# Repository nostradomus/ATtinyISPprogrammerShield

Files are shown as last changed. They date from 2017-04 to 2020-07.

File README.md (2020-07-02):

# ATtiny ISP programmer shield for Arduino UNO boards


## What

This repo provides you with all necessary info (and files) to build an Arduino shield to program Atmel's **attiny** 𝜇-controllers. For that matter, the underlying Arduino board should be loaded with the ISP-programmer sketch (built-in example).

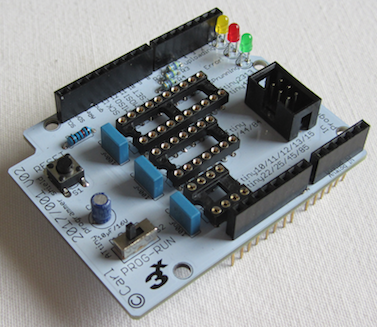
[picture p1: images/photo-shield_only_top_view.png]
Shield - topview
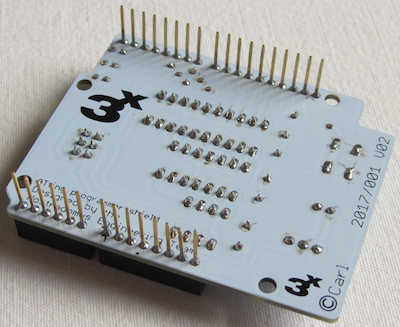
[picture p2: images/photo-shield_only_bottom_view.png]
Shield - bottomview
 

## Why

Often, one of these "tiny" chips is largely powerful enough for the design of small projects. During the design phase, I however got tired of wiring up things on a breadboard. As (like many people) I was having a spare UNO, which could serve as an ISP programmer, I decided to design a minimalistic shield to fit on top of it.  

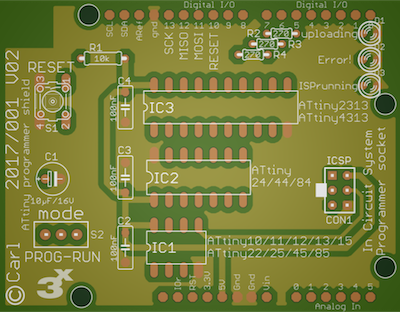
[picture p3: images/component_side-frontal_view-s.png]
PCB - component side
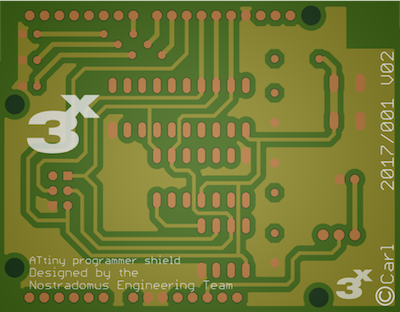
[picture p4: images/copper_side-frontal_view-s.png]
PCB - copper side
 

## How

The shield has been designed with EAGLE from AutoDesk/CadSoft. This shield [project](eagle-files/) can be opened with the free version [(download here)](http://www.autodesk.com/products/eagle/free-download). In order to keep things simple, the V1 PCB can be etched single-sided, as the top-layer only contains a couple of short connections (which can easily be replaced by wire-bridges). The V2 PCB (a real double-sided version) has optimised routing and ground-pours. Only [through-hole components](BOM.md) have been used in order to make the built also feasible for any beginner. In the [pdf-folder](pdf-files/) of this repo pdf versions of all important EAGLE views are available, for those not wanting to install EAGLE. Pay attention to print the bottom and top-layer layouts **without re-sizing** (1:1). To have the printed circuit board built by a commercial PCB-shop, the [gerber-files](gerber-files/) are also available.

Currently, unpopulated V2 boards are still available from our workshop. If interested, [contact us via   :email:](http://nostradomus.ddns.net/contactform.html).

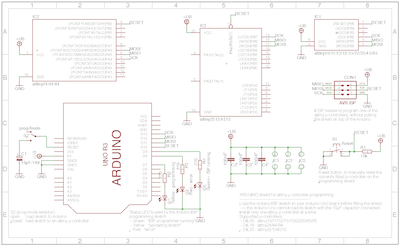
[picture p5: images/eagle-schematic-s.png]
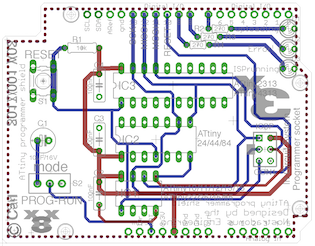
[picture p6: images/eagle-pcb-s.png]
 

## Technical details

### What’s on the board

The board is fit with 3 IC sockets (8, 14 and 20 pin), for the 3 types attiny’s. **Only one chip should be fit at a time** :exclamation: On the prototype, pin headers with double functionality have been mounted. Pins on the bottom-side to fit on the Arduino board, and feed-through female headers on the top for easy access of all Arduino connections.
The push button, is connected to the reset lines of the attiny’s with a 10kΩ pull-up resistor. When the shield is cut correctly, the reset button for the Arduino UNO itself should still be accessible. In order to make the Arduino Uno work as an ISP programmer a 10µF capacitor needs to be connected on its reset-line.
Three LED’s are available to visualise the correct functionality of the programming procedure.
An optional AVR ISP socket has been foreseen in order to use the shield as stand-alone with a commercial programmer.

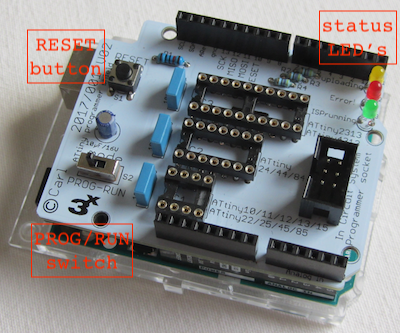
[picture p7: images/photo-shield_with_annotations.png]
V2 shield with text annotations
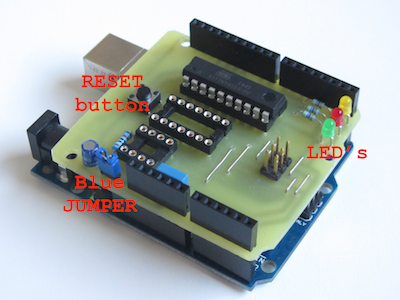
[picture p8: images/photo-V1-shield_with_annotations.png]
V1 shield with text annotations
 

#### BOM - bill of materials

Part | Value | Package | Description  
---- | ----- | ------- | -----------                            
R1     | 10kΩ           | 0207/7         | resistor                                            
R2,3,4 | 270Ω           | 0207/7         | resistor                                            
C1     | 10µF/16V       | E2,5-6E        | polarized capacitor                                 
C2,3,4 | 100nF          | C050-025X075   | capacitor                                           
LED1   | 3mm yellow     | 3mm            | LED                              
LED2   | 3mm red        | 3mm            | LED                              
LED3   | 3mm green      | 3mm            | LED                                                                                             
IC1    | 8-pin          | DIL08          | IC socket                                                            
IC2    | 14-pin         | DIL14          | IC socket                                                                     
IC3    | 20-pin         | DIL20          | IC socket                                                                     
ICSP1  | 2x3 pin-header | 2x3            | AVR ISP-6 Serial Programming Header (optional)                                 
S1     | momentary      | 6x6x6mm        | momentary tact push button
S2	    | SPDT	          | MINI SWITCH 90 | mini toggle switch
CON1   | 6-pin          | SIL06          | long needle female stackable pin header strip
CON2,3 | 8-pin          | SIL08          | long needle female stackable pin header strip
CON4   | 10-pin         | SIL10          | long needle female stackable pin header strip

### How things work

First the the [ISP-programmer sketch](sketches/ArduinoISP.ino) (built-in example) should be loaded to the Arduino UNO board. During that operation, switch S2 should be set to 'PROG' (or remove the blue jumper JP1 on a V1 board). Select “Arduino Uno” as target board in the tools-menu. Load the ISP-programmer sketch with the “UPLOAD” button. Once loaded, the jumper can be put back to send your a sketch to your attiny 𝜇-controller.

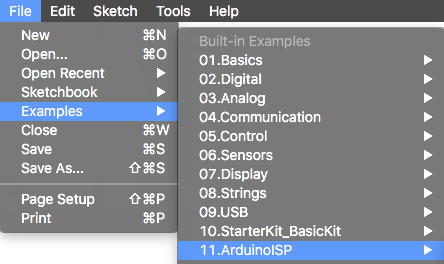
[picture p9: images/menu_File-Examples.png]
ISP example sketch
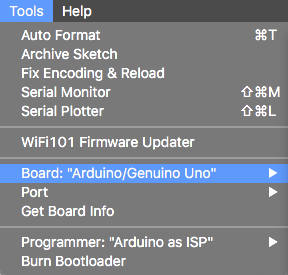
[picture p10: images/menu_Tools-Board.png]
Board selection
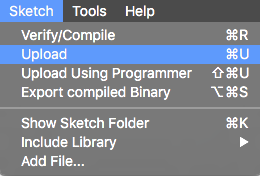
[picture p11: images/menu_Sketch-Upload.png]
Upload
  

To load a sketch to your attiny chip, make sure that the correct target board is selected in the tools-menu (you might need to download a specific library -> tools-menu, board manager). This time, use the “UPLOAD USING PROGRAMMER” option from the sketch-menu.

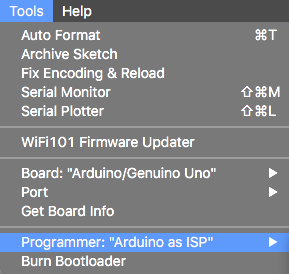
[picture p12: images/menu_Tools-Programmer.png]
Programmer selection
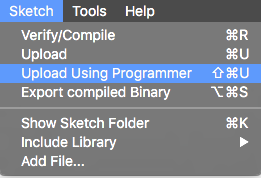
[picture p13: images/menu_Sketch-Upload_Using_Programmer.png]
Upload Using Programmer
 

The 3 LED’s will tell you how things are going :
 - Green  : ISP programmer running
 - Yellow : uploading sketch
 - Red    : error  

### Proof of concept

So far, I have tested the shield with the below list of 𝜇-controllers :
 - attiny84
 - attiny85
 - attiny2313
 - attiny4313

 Any pin-compatible 𝜇-controller should work as well :
 - 8-pin  : attiny10/11/12/13/15/22/25/45/85
 - 14-pin : attiny24/44/84
 - 20-pin : attiny2313/4313
 (on condition of using the correct settings in your Arduino programming environment)

## Contributors

If you are having any good suggestions, just drop me a line [:email:](http://nostradomus.ddns.net/contactform.html).
If feasible, I'll be happy to implement any proposed improvements.
And if you are having lots of time, I'll be happy to share the work with you ;-).

## :globe_with_meridians: License

At this moment, there is no specific license attached to this project.

So, today, if you like it, have fun with it (at your own risk of course :-D), and especially, be creative.

Oh, and when using anything from this repository, it is highly appreciated if you mention its origin.

If you would like to use any of this work (or the whole project) for commercial use, first [contact us :email:](http://nostradomus.ddns.net/contactform.html), so we can add the appropriate license, which best fits your business.

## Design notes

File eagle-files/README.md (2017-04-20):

This folder contains all files required to open the project in the EAGLE PCB software [(download here)](http://www.autodesk.com/products/eagle/free-download) : 

 - .epf : the project file as main entry point (is connected with the description file)
 - .sch : schematic file
 - .brd : pcb layout file
 
 These files should (grouped in a folder) either be copied in Eagle's project directory (see below image of the settings window). The Eagle directory settings also accept multiple paths. The Eagle syntax requires columns as path separators.

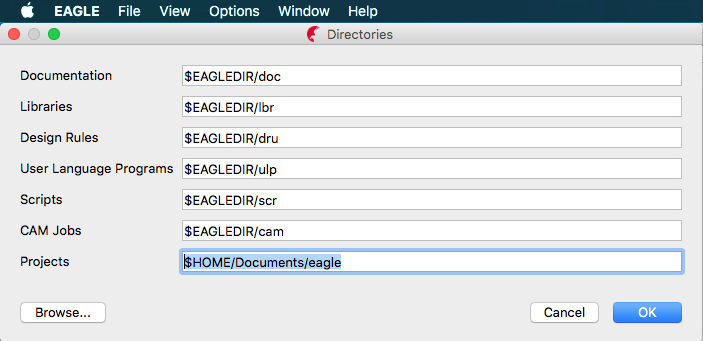
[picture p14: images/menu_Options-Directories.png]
Directory settings


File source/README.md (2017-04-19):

### This folder contains Arduino sketches related to the programming shield : 

 - The **ArduinoISP.ino** sketch has been added for informational purposes only. It has been copied from the Arduino.cc application, version 1.8 for MacOS. Please prioritise the use of the built-in example in the IDE on your system.

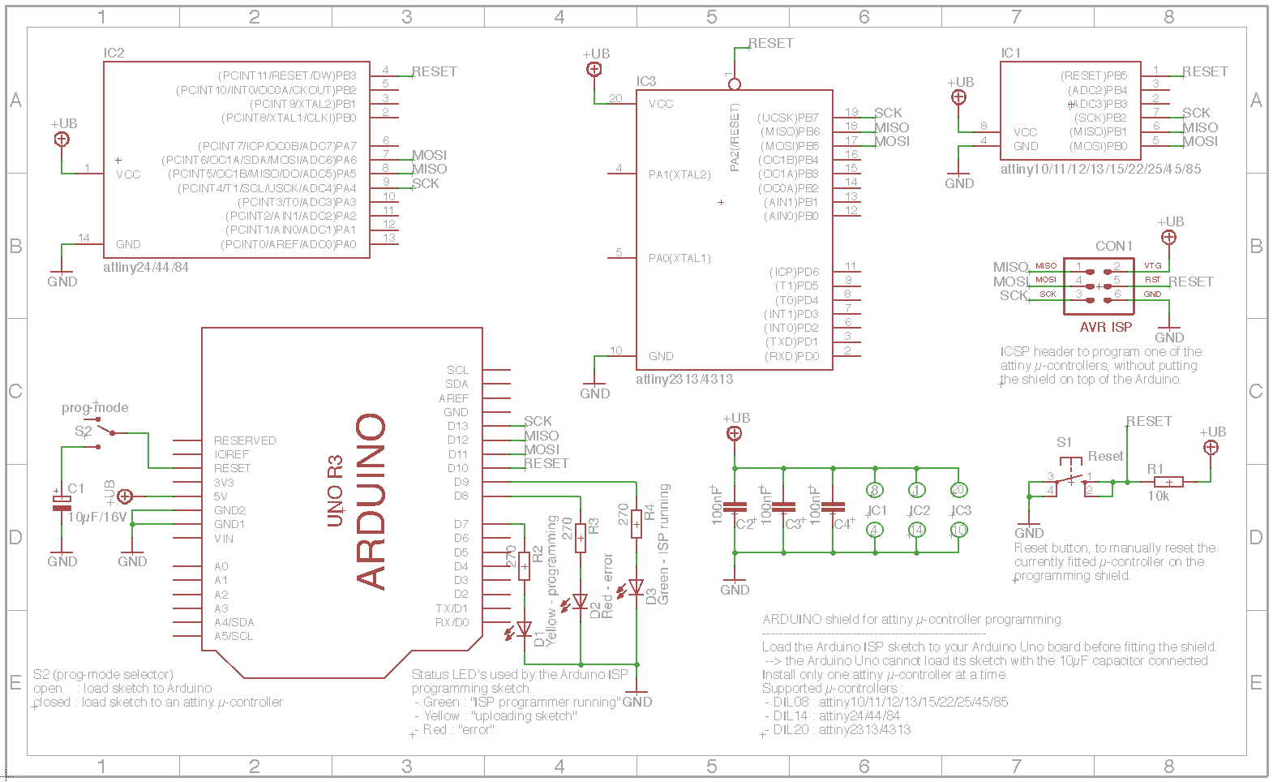
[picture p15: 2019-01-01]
images/eagle-schematic.png

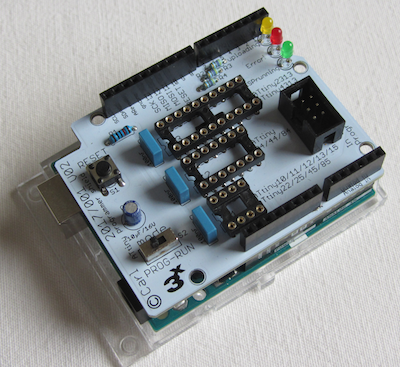
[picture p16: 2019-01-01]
images/photo-shield_fit_on_arduino-2.png

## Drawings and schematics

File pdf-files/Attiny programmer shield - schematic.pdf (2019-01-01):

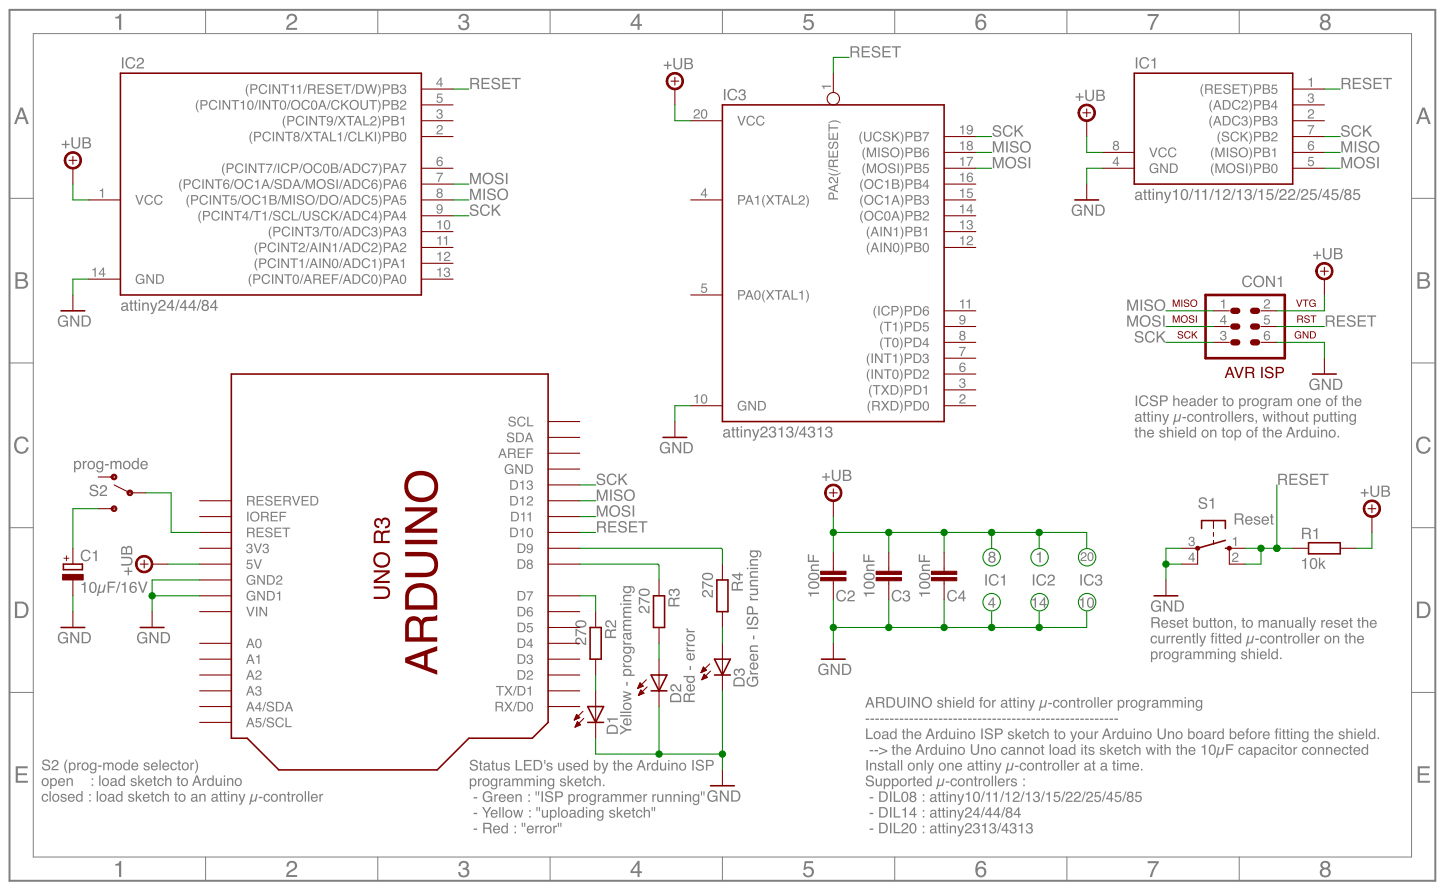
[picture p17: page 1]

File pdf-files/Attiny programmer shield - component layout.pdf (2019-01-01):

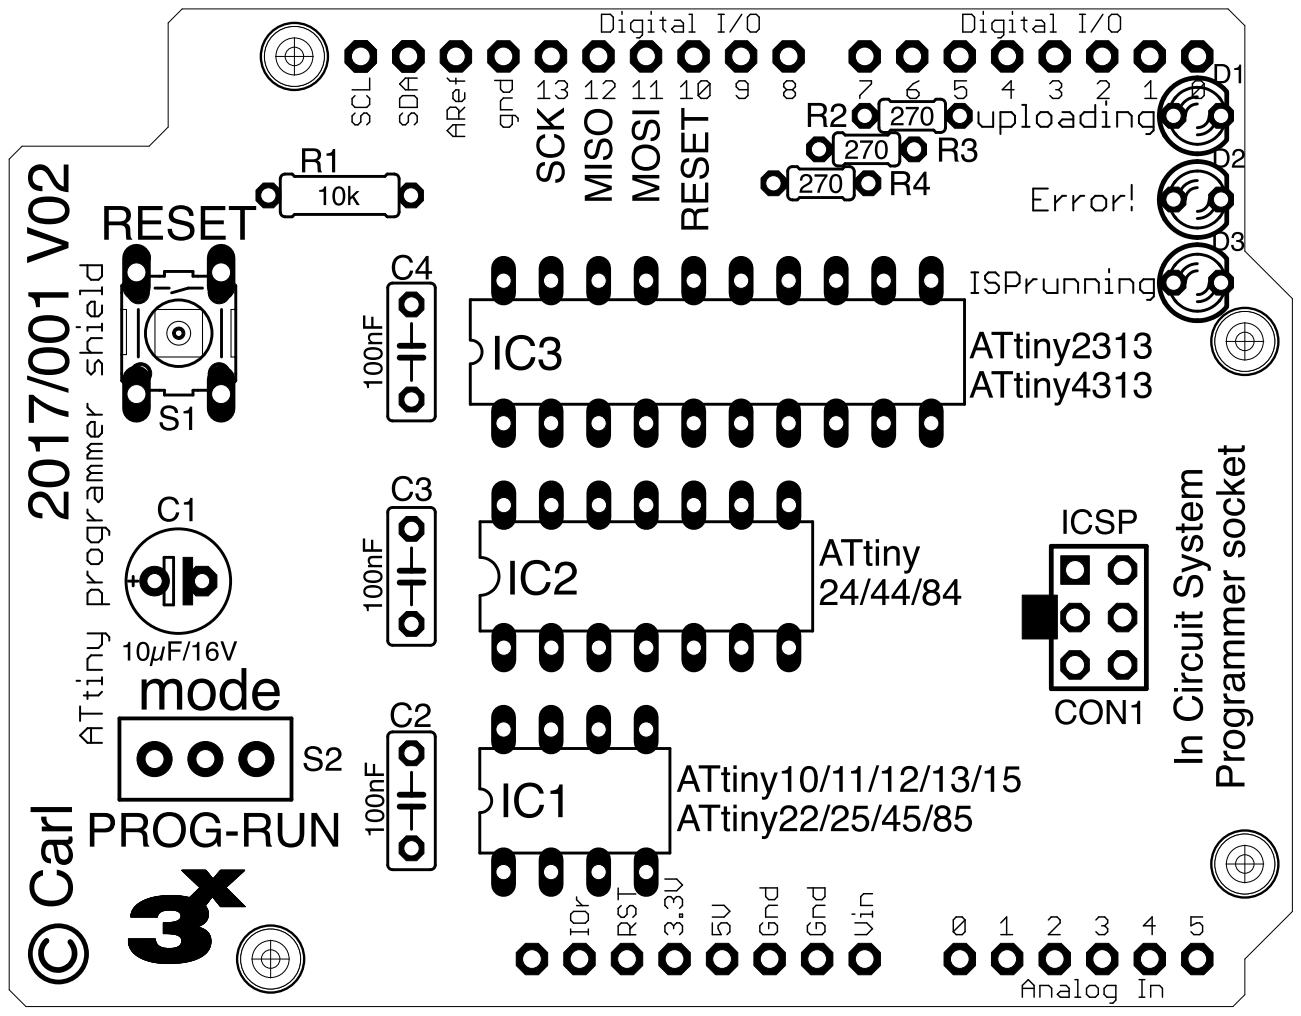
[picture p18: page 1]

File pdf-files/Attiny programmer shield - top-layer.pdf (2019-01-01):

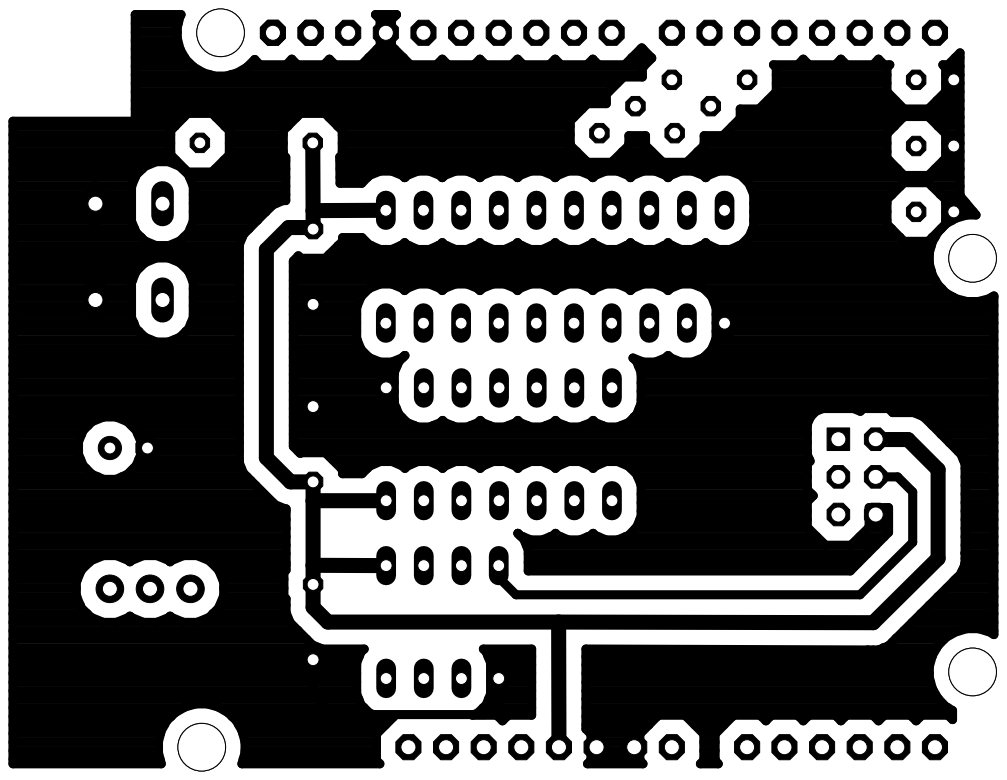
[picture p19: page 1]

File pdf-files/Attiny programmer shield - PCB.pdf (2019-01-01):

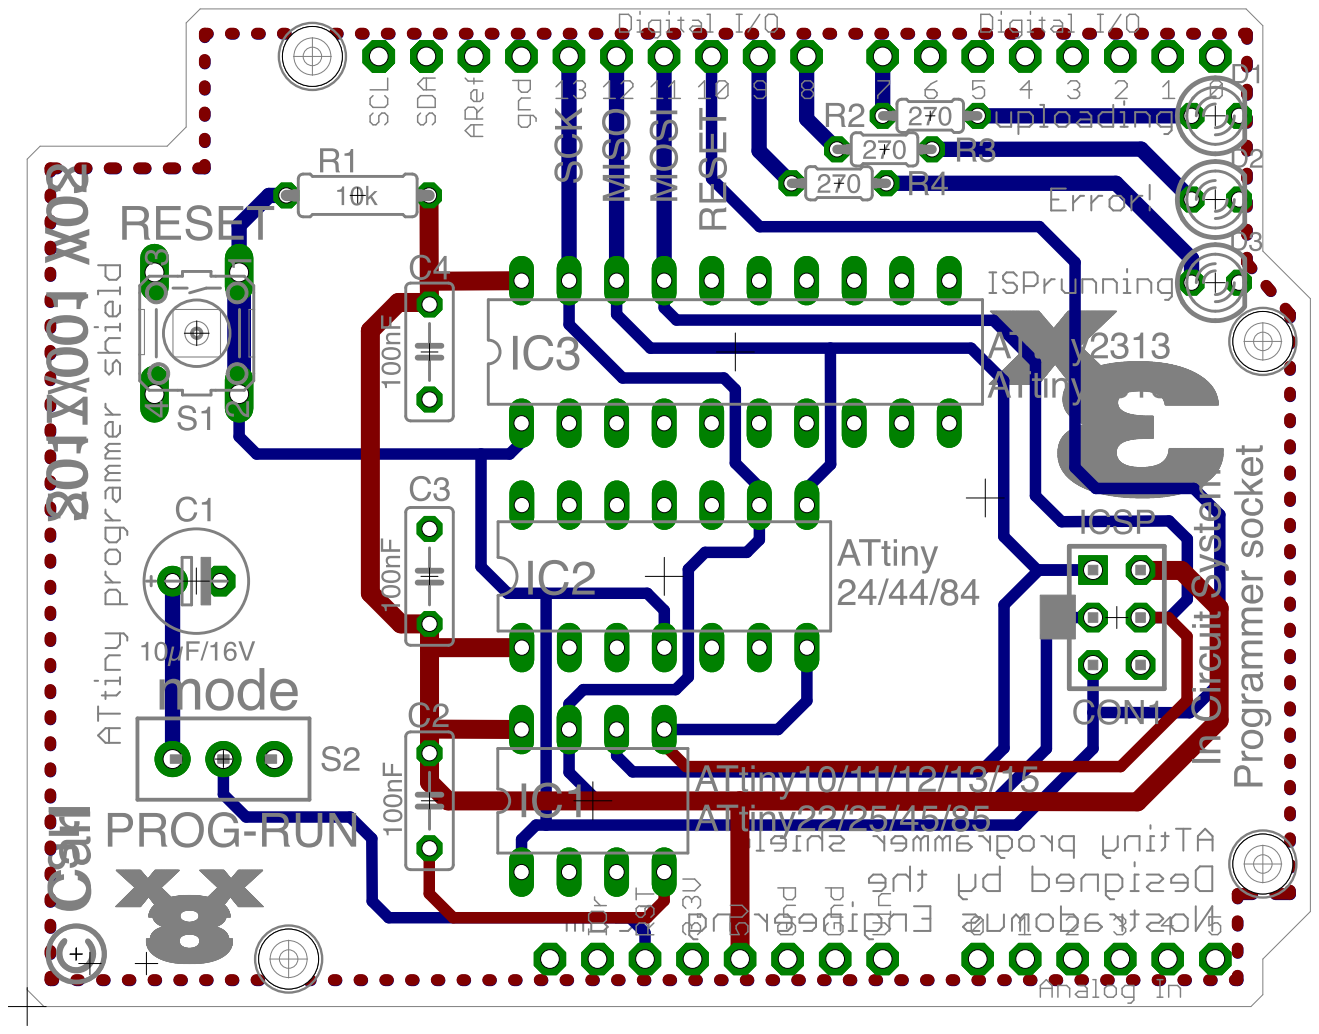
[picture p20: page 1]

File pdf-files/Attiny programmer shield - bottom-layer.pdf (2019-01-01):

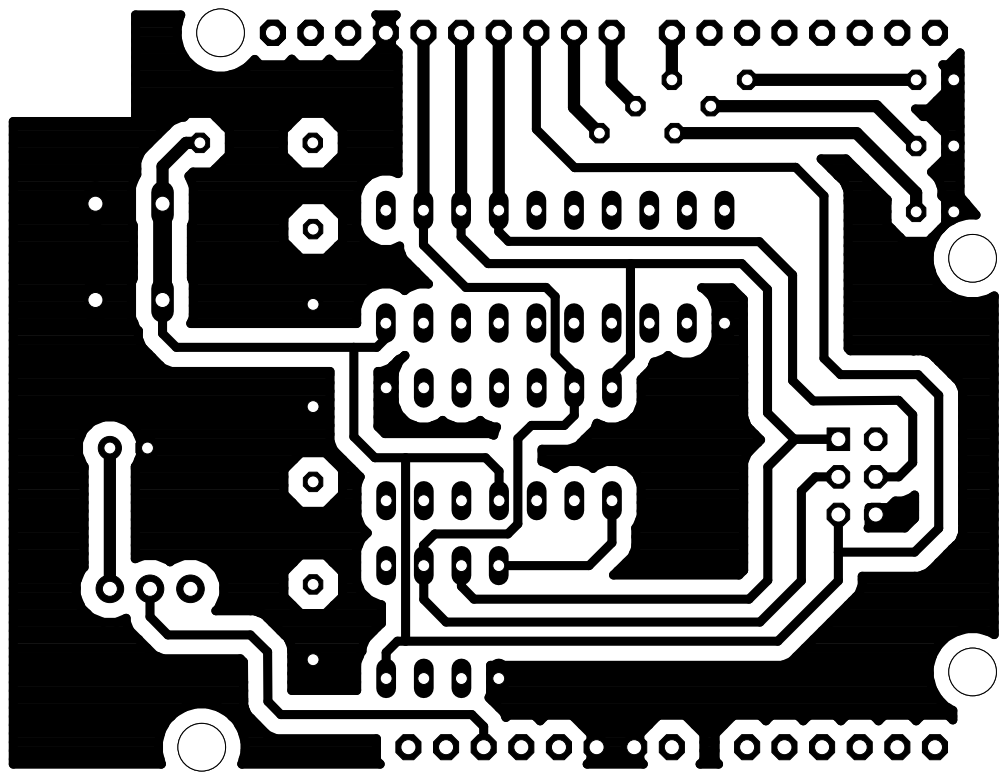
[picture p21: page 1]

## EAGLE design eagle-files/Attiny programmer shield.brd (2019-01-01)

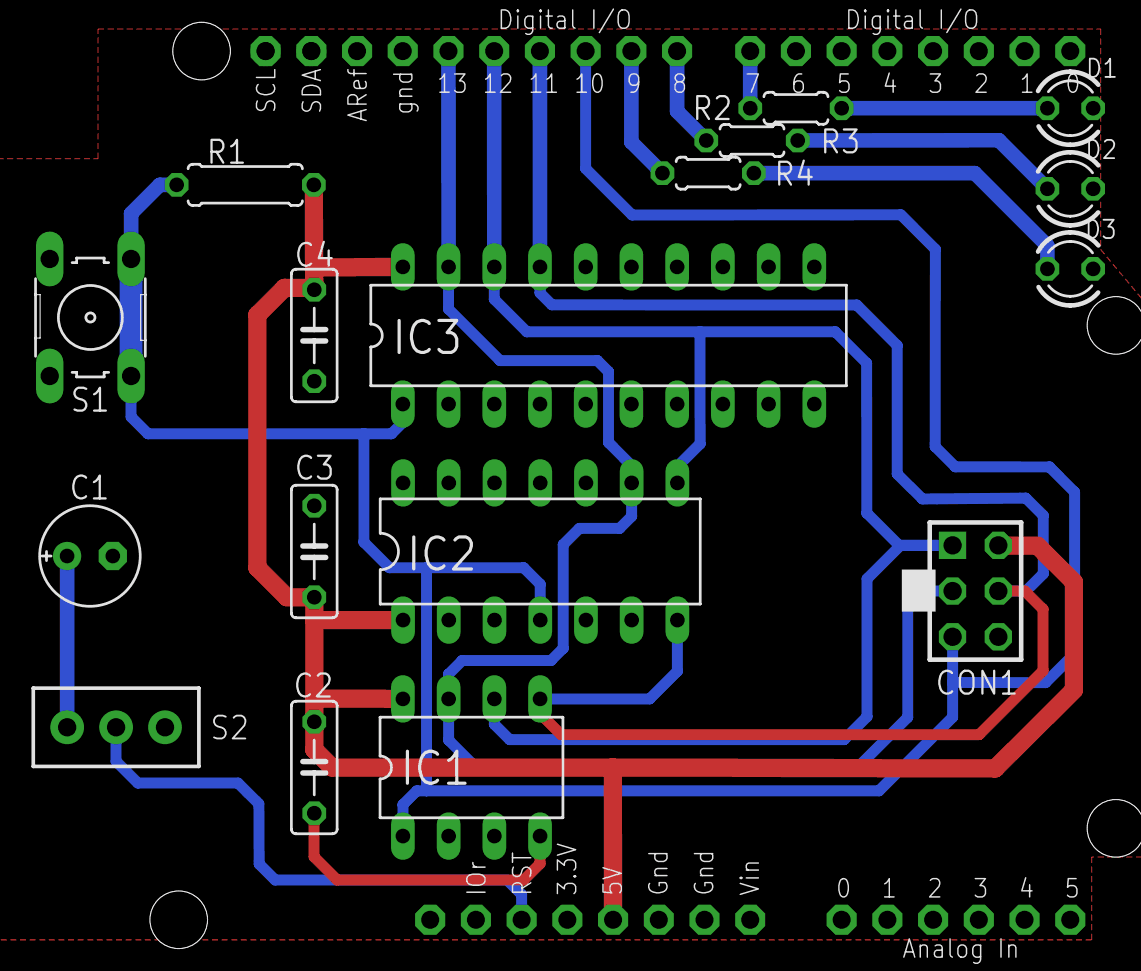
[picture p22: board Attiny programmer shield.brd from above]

Board: 2 copper layers, 23 parts (0 on the bottom side), 14 nets.

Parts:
C1: 10µF/16V; E2,5-6E
C2, C3, C4: 100nF; C050-025X075
CON1: ICSP; AVR-ISP-6
D1: Yellow - programming; LED3MM
D2: Red - error; LED3MM
D3: Green - ISP running; LED3MM
IC1: attiny10/11/12/13/15/22/25/45/85; DIL08
IC2: attiny24/44/84; DIL14
IC3: attiny2313/4313; DIL20
R1: 10k; 0207/7
R2, R3, R4: 270; 0204/5
S1: Reset; B3F-10XX
S2: prog-mode; MINI_SPDT_SWITCH-9.0X4.0MM
U$1: Arduino Uno; ARDUINO-R3
U$2: COPYRIGHT-LOGO-3-B
U$3: 3X-LOGO-10-B
U$4: COPYRIGHT-LOGO-3-T
U$5: 3X-LOGO-5-B
U$6: 3X-LOGO-5-T

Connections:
+UB: C2.2, C3.2, C4.2, CON1.2, IC1.8, IC2.1, IC3.20, R1.2, U$1.5V
GND: C1.-, C2.1, C3.1, C4.1, CON1.6, D1.K, D2.K, D3.K, IC1.4, IC2.14, IC3.10, S1.3, S1.4, U$1.GND, U$1.GND1, U$1.GND2
MISO: CON1.1, IC1.6, IC2.8, IC3.18, U$1.D12
MOSI: CON1.4, IC1.5, IC2.7, IC3.17, U$1.D11
unnamed: C1.+, S2.3
unnamed: R4.1, U$1.D9
unnamed: R2.1, U$1.D7
unnamed: R3.1, U$1.D8
unnamed: D1.A, R2.2
unnamed: D2.A, R3.2
unnamed: D3.A, R4.2
unnamed: S2.2, U$1.RESET
RESET: CON1.5, IC1.1, IC2.4, IC3.1, R1.1, S1.1, S1.2, U$1.D10
SCK: CON1.3, IC1.7, IC2.9, IC3.19, U$1.D13

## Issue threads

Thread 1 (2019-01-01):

Short between D11 and LED pin

ondras12345, 2019-01-01:
There is a short in the PCB design
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

nostradomus, 2019-01-01:
@ondras12345,
thank you for your remark.
Version V02 of this project has now been released, and does no longer contain the problem (short between LED3 and D11). All related files have been replaced in the repo, and readme's have been updated.

Closed 2019-01-01.

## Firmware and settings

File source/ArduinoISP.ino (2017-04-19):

// ArduinoISP
// Copyright (c) 2008-2011 Randall Bohn
// If you require a license, see
//     http://www.opensource.org/licenses/bsd-license.php
//
// This sketch turns the Arduino into a AVRISP
// using the following arduino pins:
//
// Pin 10 is used to reset the target microcontroller.
//
// By default, the hardware SPI pins MISO, MOSI and SCK pins are used
// to communicate with the target. On all Arduinos, these pins can be found
// on the ICSP/SPI header:
//
//               MISO °. . 5V (!) Avoid this pin on Due, Zero...
//               SCK   . . MOSI
//                     . . GND
//
// On some Arduinos (Uno,...), pins MOSI, MISO and SCK are the same pins
// as digital pin 11, 12 and 13, respectively. That is why many tutorials
// instruct you to hook up the target to these pins. If you find this wiring
// more practical, have a define USE_OLD_STYLE_WIRING. This will work even
// even when not using an Uno. (On an Uno this is not needed).
//
// Alternatively you can use any other digital pin by configuring software ('BitBanged')
// SPI and having appropriate defines for PIN_MOSI, PIN_MISO and PIN_SCK.
// 
// IMPORTANT: When using an Arduino that is not 5V tolerant (Due, Zero, ...)
// as the programmer, make sure to not expose any of the programmer's pins to 5V.
// A simple way to accomplish this is to power the complete system (programmer
// and target) at 3V3.
//
// Put an LED (with resistor) on the following pins:
// 9: Heartbeat   - shows the programmer is running
// 8: Error       - Lights up if something goes wrong (use red if that makes sense)
// 7: Programming - In communication with the slave
//

#include "Arduino.h"
#undef SERIAL


#define PROG_FLICKER true

// Configure SPI clock (in Hz).
// E.g. for an attiny @128 kHz: the datasheet states that both the high
// and low spi clock pulse must be > 2 cpu cycles, so take 3 cycles i.e.
// divide target f_cpu by 6:
//     #define SPI_CLOCK            (128000/6)
//
// A clock slow enough for an attiny85 @ 1MHz, is a reasonable default:

#define SPI_CLOCK 		(1000000/6)


// Select hardware or software SPI, depending on SPI clock.
// Currently only for AVR, for other archs (Due, Zero,...),
// hardware SPI is probably too fast anyway.

#if defined(ARDUINO_ARCH_AVR)

#if SPI_CLOCK > (F_CPU / 128)
#define USE_HARDWARE_SPI
#endif

#endif

// Configure which pins to use:

// The standard pin configuration.
#ifndef ARDUINO_HOODLOADER2 

#define RESET     10 // Use pin 10 to reset the target rather than SS
#define LED_HB    9
#define LED_ERR   8
#define LED_PMODE 7

// Uncomment following line to use the old Uno style wiring
// (using pin 11, 12 and 13 instead of the SPI header) on Leonardo, Due...

// #define USE_OLD_STYLE_WIRING

#ifdef USE_OLD_STYLE_WIRING

#define PIN_MOSI	11
#define PIN_MISO	12
#define PIN_SCK		13

#endif

// HOODLOADER2 means running sketches on the atmega16u2 
// serial converter chips on Uno or Mega boards.
// We must use pins that are broken out:
#else 

#define RESET     	4
#define LED_HB    	7
#define LED_ERR   	6
#define LED_PMODE 	5

#endif

// By default, use hardware SPI pins:
#ifndef PIN_MOSI
#define PIN_MOSI 	MOSI
#endif

#ifndef PIN_MISO
#define PIN_MISO 	MISO
#endif

#ifndef PIN_SCK
#define PIN_SCK 	SCK
#endif

// Force bitbanged SPI if not using the hardware SPI pins:
#if (PIN_MISO != MISO) ||  (PIN_MOSI != MOSI) || (PIN_SCK != SCK)
#undef USE_HARDWARE_SPI
#endif


// Configure the serial port to use.
//
// Prefer the USB virtual serial port (aka. native USB port), if the Arduino has one:
//   - it does not autoreset (except for the magic baud rate of 1200).
//   - it is more reliable because of USB handshaking.
//
// Leonardo and similar have an USB virtual serial port: 'Serial'.
// Due and Zero have an USB virtual serial port: 'SerialUSB'.
//
// On the Due and Zero, 'Serial' can be used too, provided you disable autoreset.
// To use 'Serial': #define SERIAL Serial

#ifdef SERIAL_PORT_USBVIRTUAL
#define SERIAL SERIAL_PORT_USBVIRTUAL
#else
#define SERIAL Serial
#endif


// Configure the baud rate:

#define BAUDRATE	19200
// #define BAUDRATE	115200
// #define BAUDRATE	1000000


#define HWVER 2
#define SWMAJ 1
#define SWMIN 18

// STK Definitions
#define STK_OK      0x10
#define STK_FAILED  0x11
#define STK_UNKNOWN 0x12
#define STK_INSYNC  0x14
#define STK_NOSYNC  0x15
#define CRC_EOP     0x20 //ok it is a space...

void pulse(int pin, int times);

#ifdef USE_HARDWARE_SPI
#include "SPI.h"
#else

#define SPI_MODE0 0x00

class SPISettings {
public:
  // clock is in Hz
  SPISettings(uint32_t clock, uint8_t bitOrder, uint8_t dataMode) : clock(clock){
    (void) bitOrder;
    (void) dataMode;
  };

private:
  uint32_t clock;

friend class BitBangedSPI;
};

class BitBangedSPI {
public:
  void begin() {
    digitalWrite(PIN_SCK, LOW);
    digitalWrite(PIN_MOSI, LOW);
    pinMode(PIN_SCK, OUTPUT);
    pinMode(PIN_MOSI, OUTPUT);
    pinMode(PIN_MISO, INPUT);
  }

  void beginTransaction(SPISettings settings) {
    pulseWidth = (500000 + settings.clock - 1) / settings.clock;
    if (pulseWidth == 0)
      pulseWidth = 1;
  }

  void end() {}

  uint8_t transfer (uint8_t b) {
    for (unsigned int i = 0; i < 8; ++i) {
      digitalWrite(PIN_MOSI, (b & 0x80) ? HIGH : LOW);
      digitalWrite(PIN_SCK, HIGH);
      delayMicroseconds(pulseWidth);
      b = (b << 1) | digitalRead(PIN_MISO);
      digitalWrite(PIN_SCK, LOW); // slow pulse
      delayMicroseconds(pulseWidth);
    }
    return b;
  }

private:
  unsigned long pulseWidth; // in microseconds
};

static BitBangedSPI SPI;

#endif

void setup() {
  SERIAL.begin(BAUDRATE);

  pinMode(LED_PMODE, OUTPUT);
  pulse(LED_PMODE, 2);
  pinMode(LED_ERR, OUTPUT);
  pulse(LED_ERR, 2);
  pinMode(LED_HB, OUTPUT);
  pulse(LED_HB, 2);

}

int error = 0;
int pmode = 0;
// address for reading and writing, set by 'U' command
unsigned int here;
uint8_t buff[256]; // global block storage

#define beget16(addr) (*addr * 256 + *(addr+1) )
typedef struct param {
  uint8_t devicecode;
  uint8_t revision;
  uint8_t progtype;
  uint8_t parmode;
  uint8_t polling;
  uint8_t selftimed;
  uint8_t lockbytes;
  uint8_t fusebytes;
  uint8_t flashpoll;
  uint16_t eeprompoll;
  uint16_t pagesize;
  uint16_t eepromsize;
  uint32_t flashsize;
}
parameter;

parameter param;

// this provides a heartbeat on pin 9, so you can tell the software is running.
uint8_t hbval = 128;
int8_t hbdelta = 8;
void heartbeat() {
  static unsigned long last_time = 0;
  unsigned long now = millis();
  if ((now - last_time) < 40)
    return;
  last_time = now;
  if (hbval > 192) hbdelta = -hbdelta;
  if (hbval < 32) hbdelta = -hbdelta;
  hbval += hbdelta;
  analogWrite(LED_HB, hbval);
}

static bool rst_active_high;

void reset_target(bool reset) {
  digitalWrite(RESET, ((reset && rst_active_high) || (!reset && !rst_active_high)) ? HIGH : LOW);
}

void loop(void) {
  // is pmode active?
  if (pmode) {
    digitalWrite(LED_PMODE, HIGH);
  } else {
    digitalWrite(LED_PMODE, LOW);
  }
  // is there an error?
  if (error) {
    digitalWrite(LED_ERR, HIGH);
  } else {
    digitalWrite(LED_ERR, LOW);
  }

  // light the heartbeat LED
  heartbeat();
  if (SERIAL.available()) {
    avrisp();
  }
}

uint8_t getch() {
  while (!SERIAL.available());
  return SERIAL.read();
}
void fill(int n) {
  for (int x = 0; x < n; x++) {
    buff[x] = getch();
  }
}

#define PTIME 30
void pulse(int pin, int times) {
  do {
    digitalWrite(pin, HIGH);
    delay(PTIME);
    digitalWrite(pin, LOW);
    delay(PTIME);
  } while (times--);
}

void prog_lamp(int state) {
  if (PROG_FLICKER) {
    digitalWrite(LED_PMODE, state);
  }
}

uint8_t spi_transaction(uint8_t a, uint8_t b, uint8_t c, uint8_t d) {
  SPI.transfer(a);
  SPI.transfer(b);
  SPI.transfer(c);
  return SPI.transfer(d);
}

void empty_reply() {
  if (CRC_EOP == getch()) {
    SERIAL.print((char)STK_INSYNC);
    SERIAL.print((char)STK_OK);
  } else {
    error++;
    SERIAL.print((char)STK_NOSYNC);
  }
}

void breply(uint8_t b) {
  if (CRC_EOP == getch()) {
    SERIAL.print((char)STK_INSYNC);
    SERIAL.print((char)b);
    SERIAL.print((char)STK_OK);
  } else {
    error++;
    SERIAL.print((char)STK_NOSYNC);
  }
}

void get_version(uint8_t c) {
  switch (c) {
    case 0x80:
      breply(HWVER);
      break;
    case 0x81:
      breply(SWMAJ);
      break;
    case 0x82:
      breply(SWMIN);
      break;
    case 0x93:
      breply('S'); // serial programmer
      break;
    default:
      breply(0);
  }
}

void set_parameters() {
  // call this after reading paramter packet into buff[]
  param.devicecode = buff[0];
  param.revision   = buff[1];
  param.progtype   = buff[2];
  param.parmode    = buff[3];
  param.polling    = buff[4];
  param.selftimed  = buff[5];
  param.lockbytes  = buff[6];
  param.fusebytes  = buff[7];
  param.flashpoll  = buff[8];
  // ignore buff[9] (= buff[8])
  // following are 16 bits (big endian)
  param.eeprompoll = beget16(&buff[10]);
  param.pagesize   = beget16(&buff[12]);
  param.eepromsize = beget16(&buff[14]);

  // 32 bits flashsize (big endian)
  param.flashsize = buff[16] * 0x01000000
                    + buff[17] * 0x00010000
                    + buff[18] * 0x00000100
                    + buff[19];

  // avr devices have active low reset, at89sx are active high
  rst_active_high = (param.devicecode >= 0xe0);
}

void start_pmode() {

  // Reset target before driving PIN_SCK or PIN_MOSI

  // SPI.begin() will configure SS as output,
  // so SPI master mode is selected.
  // We have defined RESET as pin 10,
  // which for many arduino's is not the SS pin.
  // So we have to configure RESET as output here,
  // (reset_target() first sets the correct level)
  reset_target(true);
  pinMode(RESET, OUTPUT);
  SPI.begin();
  SPI.beginTransaction(SPISettings(SPI_CLOCK, MSBFIRST, SPI_MODE0));

  // See avr datasheets, chapter "SERIAL_PRG Programming Algorithm":

  // Pulse RESET after PIN_SCK is low:
  digitalWrite(PIN_SCK, LOW);
  delay(20); // discharge PIN_SCK, value arbitrally chosen
  reset_target(false);
  // Pulse must be minimum 2 target CPU clock cycles
  // so 100 usec is ok for CPU speeds above 20KHz
  delayMicroseconds(100);
  reset_target(true);

  // Send the enable programming command:
  delay(50); // datasheet: must be > 20 msec
  spi_transaction(0xAC, 0x53, 0x00, 0x00);
  pmode = 1;
}

void end_pmode() {
  SPI.end();
  // We're about to take the target out of reset
  // so configure SPI pins as input
  pinMode(PIN_MOSI, INPUT);
  pinMode(PIN_SCK, INPUT);
  reset_target(false);
  pinMode(RESET, INPUT);
  pmode = 0;
}

void universal() {
  uint8_t ch;

  fill(4);
  ch = spi_transaction(buff[0], buff[1], buff[2], buff[3]);
  breply(ch);
}

void flash(uint8_t hilo, unsigned int addr, uint8_t data) {
  spi_transaction(0x40 + 8 * hilo,
                  addr >> 8 & 0xFF,
                  addr & 0xFF,
                  data);
}
void commit(unsigned int addr) {
  if (PROG_FLICKER) {
    prog_lamp(LOW);
  }
  spi_transaction(0x4C, (addr >> 8) & 0xFF, addr & 0xFF, 0);
  if (PROG_FLICKER) {
    delay(PTIME);
    prog_lamp(HIGH);
  }
}

unsigned int current_page() {
  if (param.pagesize == 32) {
    return here & 0xFFFFFFF0;
  }
  if (param.pagesize == 64) {
    return here & 0xFFFFFFE0;
  }
  if (param.pagesize == 128) {
    return here & 0xFFFFFFC0;
  }
  if (param.pagesize == 256) {
    return here & 0xFFFFFF80;
  }
  return here;
}


void write_flash(int length) {
  fill(length);
  if (CRC_EOP == getch()) {
    SERIAL.print((char) STK_INSYNC);
    SERIAL.print((char) write_flash_pages(length));
  } else {
    error++;
    SERIAL.print((char) STK_NOSYNC);
  }
}

uint8_t write_flash_pages(int length) {
  int x = 0;
  unsigned int page = current_page();
  while (x < length) {
    if (page != current_page()) {
      commit(page);
      page = current_page();
    }
    flash(LOW, here, buff[x++]);
    flash(HIGH, here, buff[x++]);
    here++;
  }

  commit(page);

  return STK_OK;
}

#define EECHUNK (32)
uint8_t write_eeprom(unsigned int length) {
  // here is a word address, get the byte address
  unsigned int start = here * 2;
  unsigned int remaining = length;
  if (length > param.eepromsize) {
    error++;
    return STK_FAILED;
  }
  while (remaining > EECHUNK) {
    write_eeprom_chunk(start, EECHUNK);
    start += EECHUNK;
    remaining -= EECHUNK;
  }
  write_eeprom_chunk(start, remaining);
  return STK_OK;
}
// write (length) bytes, (start) is a byte address
uint8_t write_eeprom_chunk(unsigned int start, unsigned int length) {
  // this writes byte-by-byte,
  // page writing may be faster (4 bytes at a time)
  fill(length);
  prog_lamp(LOW);
  for (unsigned int x = 0; x < length; x++) {
    unsigned int addr = start + x;
    spi_transaction(0xC0, (addr >> 8) & 0xFF, addr & 0xFF, buff[x]);
    delay(45);
  }
  prog_lamp(HIGH);
  return STK_OK;
}

void program_page() {
  char result = (char) STK_FAILED;
  unsigned int length = 256 * getch();
  length += getch();
  char memtype = getch();
  // flash memory @here, (length) bytes
  if (memtype == 'F') {
    write_flash(length);
    return;
  }
  if (memtype == 'E') {
    result = (char)write_eeprom(length);
    if (CRC_EOP == getch()) {
      SERIAL.print((char) STK_INSYNC);
      SERIAL.print(result);
    } else {
      error++;
      SERIAL.print((char) STK_NOSYNC);
    }
    return;
  }
  SERIAL.print((char)STK_FAILED);
  return;
}

uint8_t flash_read(uint8_t hilo, unsigned int addr) {
  return spi_transaction(0x20 + hilo * 8,
                         (addr >> 8) & 0xFF,
                         addr & 0xFF,
                         0);
}

char flash_read_page(int length) {
  for (int x = 0; x < length; x += 2) {
    uint8_t low = flash_read(LOW, here);
    SERIAL.print((char) low);
    uint8_t high = flash_read(HIGH, here);
    SERIAL.print((char) high);
    here++;
  }
  return STK_OK;
}

char eeprom_read_page(int length) {
  // here again we have a word address
  int start = here * 2;
  for (int x = 0; x < length; x++) {
    int addr = start + x;
    uint8_t ee = spi_transaction(0xA0, (addr >> 8) & 0xFF, addr & 0xFF, 0xFF);
    SERIAL.print((char) ee);
  }
  return STK_OK;
}

void read_page() {
  char result = (char)STK_FAILED;
  int length = 256 * getch();
  length += getch();
  char memtype = getch();
  if (CRC_EOP != getch()) {
    error++;
    SERIAL.print((char) STK_NOSYNC);
    return;
  }
  SERIAL.print((char) STK_INSYNC);
  if (memtype == 'F') result = flash_read_page(length);
  if (memtype == 'E') result = eeprom_read_page(length);
  SERIAL.print(result);
}

void read_signature() {
  if (CRC_EOP != getch()) {
    error++;
    SERIAL.print((char) STK_NOSYNC);
    return;
  }
  SERIAL.print((char) STK_INSYNC);
  uint8_t high = spi_transaction(0x30, 0x00, 0x00, 0x00);
  SERIAL.print((char) high);
  uint8_t middle = spi_transaction(0x30, 0x00, 0x01, 0x00);
  SERIAL.print((char) middle);
  uint8_t low = spi_transaction(0x30, 0x00, 0x02, 0x00);
  SERIAL.print((char) low);
  SERIAL.print((char) STK_OK);
}
//////////////////////////////////////////
//////////////////////////////////////////


////////////////////////////////////
////////////////////////////////////
void avrisp() {
  uint8_t ch = getch();
  switch (ch) {
    case '0': // signon
      error = 0;
      empty_reply();
      break;
    case '1':
      if (getch() == CRC_EOP) {
        SERIAL.print((char) STK_INSYNC);
        SERIAL.print("AVR ISP");
        SERIAL.print((char) STK_OK);
      }
      else {
        error++;
        SERIAL.print((char) STK_NOSYNC);
      }
      break;
    case 'A':
      get_version(getch());
      break;
    case 'B':
      fill(20);
      set_parameters();
      empty_reply();
      break;
    case 'E': // extended parameters - ignore for now
      fill(5);
      empty_reply();
      break;
    case 'P':
      if (!pmode)
        start_pmode();
      empty_reply();
      break;
    case 'U': // set address (word)
      here = getch();
      here += 256 * getch();
      empty_reply();
      break;

    case 0x60: //STK_PROG_FLASH
      getch(); // low addr
      getch(); // high addr
      empty_reply();
      break;
    case 0x61: //STK_PROG_DATA
      getch(); // data
      empty_reply();
      break;

    case 0x64: //STK_PROG_PAGE
      program_page();
      break;

    case 0x74: //STK_READ_PAGE 't'
      read_page();
      break;

    case 'V': //0x56
      universal();
      break;
    case 'Q': //0x51
      error = 0;
      end_pmode();
      empty_reply();
      break;

    case 0x75: //STK_READ_SIGN 'u'
      read_signature();
      break;

    // expecting a command, not CRC_EOP
    // this is how we can get back in sync
    case CRC_EOP:
      error++;
      SERIAL.print((char) STK_NOSYNC);
      break;

    // anything else we will return STK_UNKNOWN
    default:
      error++;
      if (CRC_EOP == getch())
        SERIAL.print((char)STK_UNKNOWN);
      else
        SERIAL.print((char)STK_NOSYNC);
  }
}
